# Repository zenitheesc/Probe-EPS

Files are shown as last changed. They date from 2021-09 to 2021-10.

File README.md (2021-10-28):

<h1 align="center" style="color:white; background-color:black">Probe-EPS</h1>
<h4 align="center">Eletrical power system for stratospheric probes, using Zenith Stack</h4>

<p align="center">
	<a href="http://zenith.eesc.usp.br/">
    
    </a>
    <a href="https://eesc.usp.br/">
    
    </a>
    <a href="https://github.com/zenitheesc/Probe-EPS/blob/main/LICENSE">
    
    </a>
    <a href="https://github.com/zenitheesc/Probe-EPS/issues">
    
    </a>
    <a href="https://github.com/zenitheesc/Probe-EPS/commits/main">
    
    </a>
    <a href="https://github.com/zenitheesc/Probe-EPS/graphs/contributors">
    
    </a>
    <a href="https://github.com/zenitheesc/Probe-EPS/commits/main">
    
    </a>
    <a href="https://github.com/zenitheesc/Probe-EPS/issues">
    
    </a>
    <a href="https://github.com/zenitheesc/Probe-EPS/pulls">
    
    </a>
</p>

<p align="center">
    <a href="#environment-and-tools">Environment and Tools</a> •
    <a href="#z-hub">Z-Hub</a> •
    <a href="#aroca-(battery)-eps">Aroca (Battery) EPS</a> •
    <a href="#london-(power)-eps">London (Power) EPS</a>
</p>

This configuration of the Eletrical power system requires a board that monitors the charger and battery, in addition to performing thermal control.

## Environment and tools

This system was designed using Eagle v.9.4.2

## Z-Hub

<p align = "center">
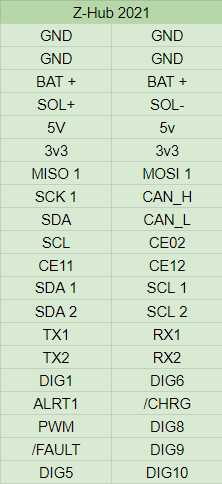
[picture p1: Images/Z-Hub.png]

</p>

<a href="https://github.com/zenitheesc/Probe-EPS/tree/main/Hardware/Aroca_EPS-v.2.0"><h2>Aroca (Battery) EPS</h2></a>

<p align = "center">
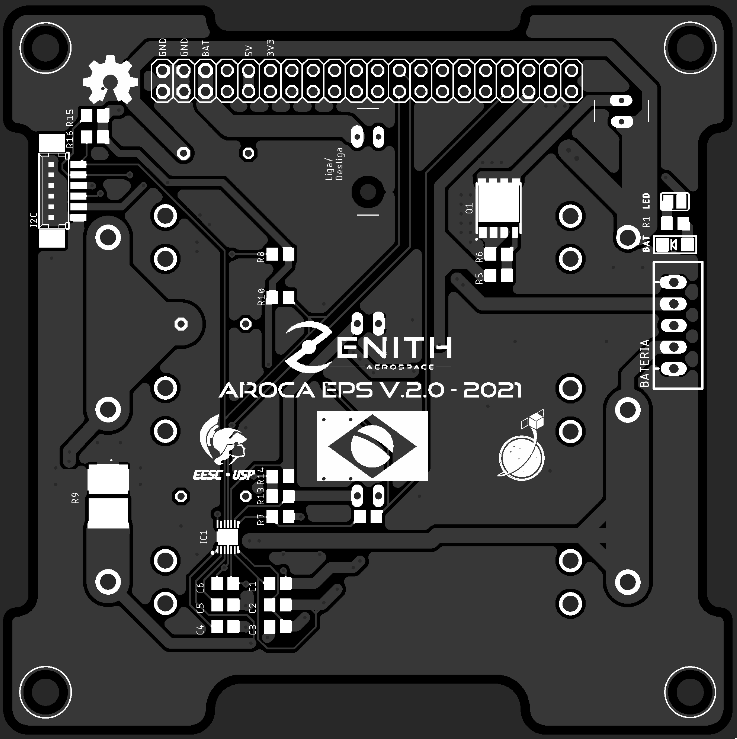
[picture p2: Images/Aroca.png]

</p>

This subsystem is primarily responsible for the active thermal control of the batteries, in addition to supporting battery monitoring and load balancing

<a href="https://github.com/zenitheesc/Probe-EPS/tree/main/Hardware/London_EPS-v.2.0"><h2>London (Power) EPS</h2></a>

<p align = "center">
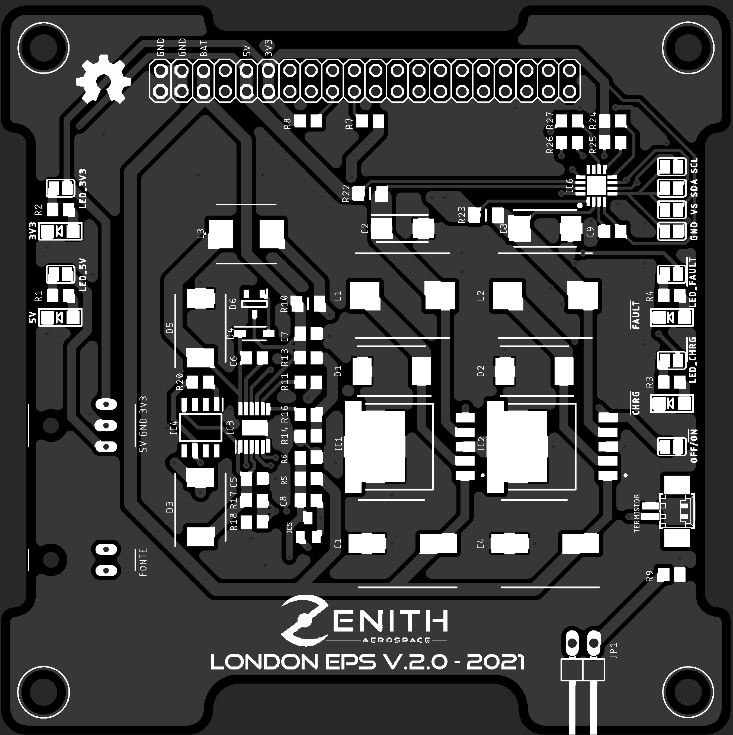
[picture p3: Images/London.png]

</p>

Functioning as an extension of the previous subsystem, it performs conversions of battery voltage levels to the levels requested within the hardware, making the necessary distribution, as well as controlling the loading of batteries through solar panels.

---

<p align="center">
    <a href="http://zenith.eesc.usp.br">
    
    </a> 
    <a href="https://www.facebook.com/zenitheesc">
    
    </a> 
    <a href="https://www.instagram.com/zenith_eesc/">
    
    </a>

</p>
<p align = "center">
<a href="zenith.eesc@gmail.com">zenith.eesc@gmail.com</a>
</p>

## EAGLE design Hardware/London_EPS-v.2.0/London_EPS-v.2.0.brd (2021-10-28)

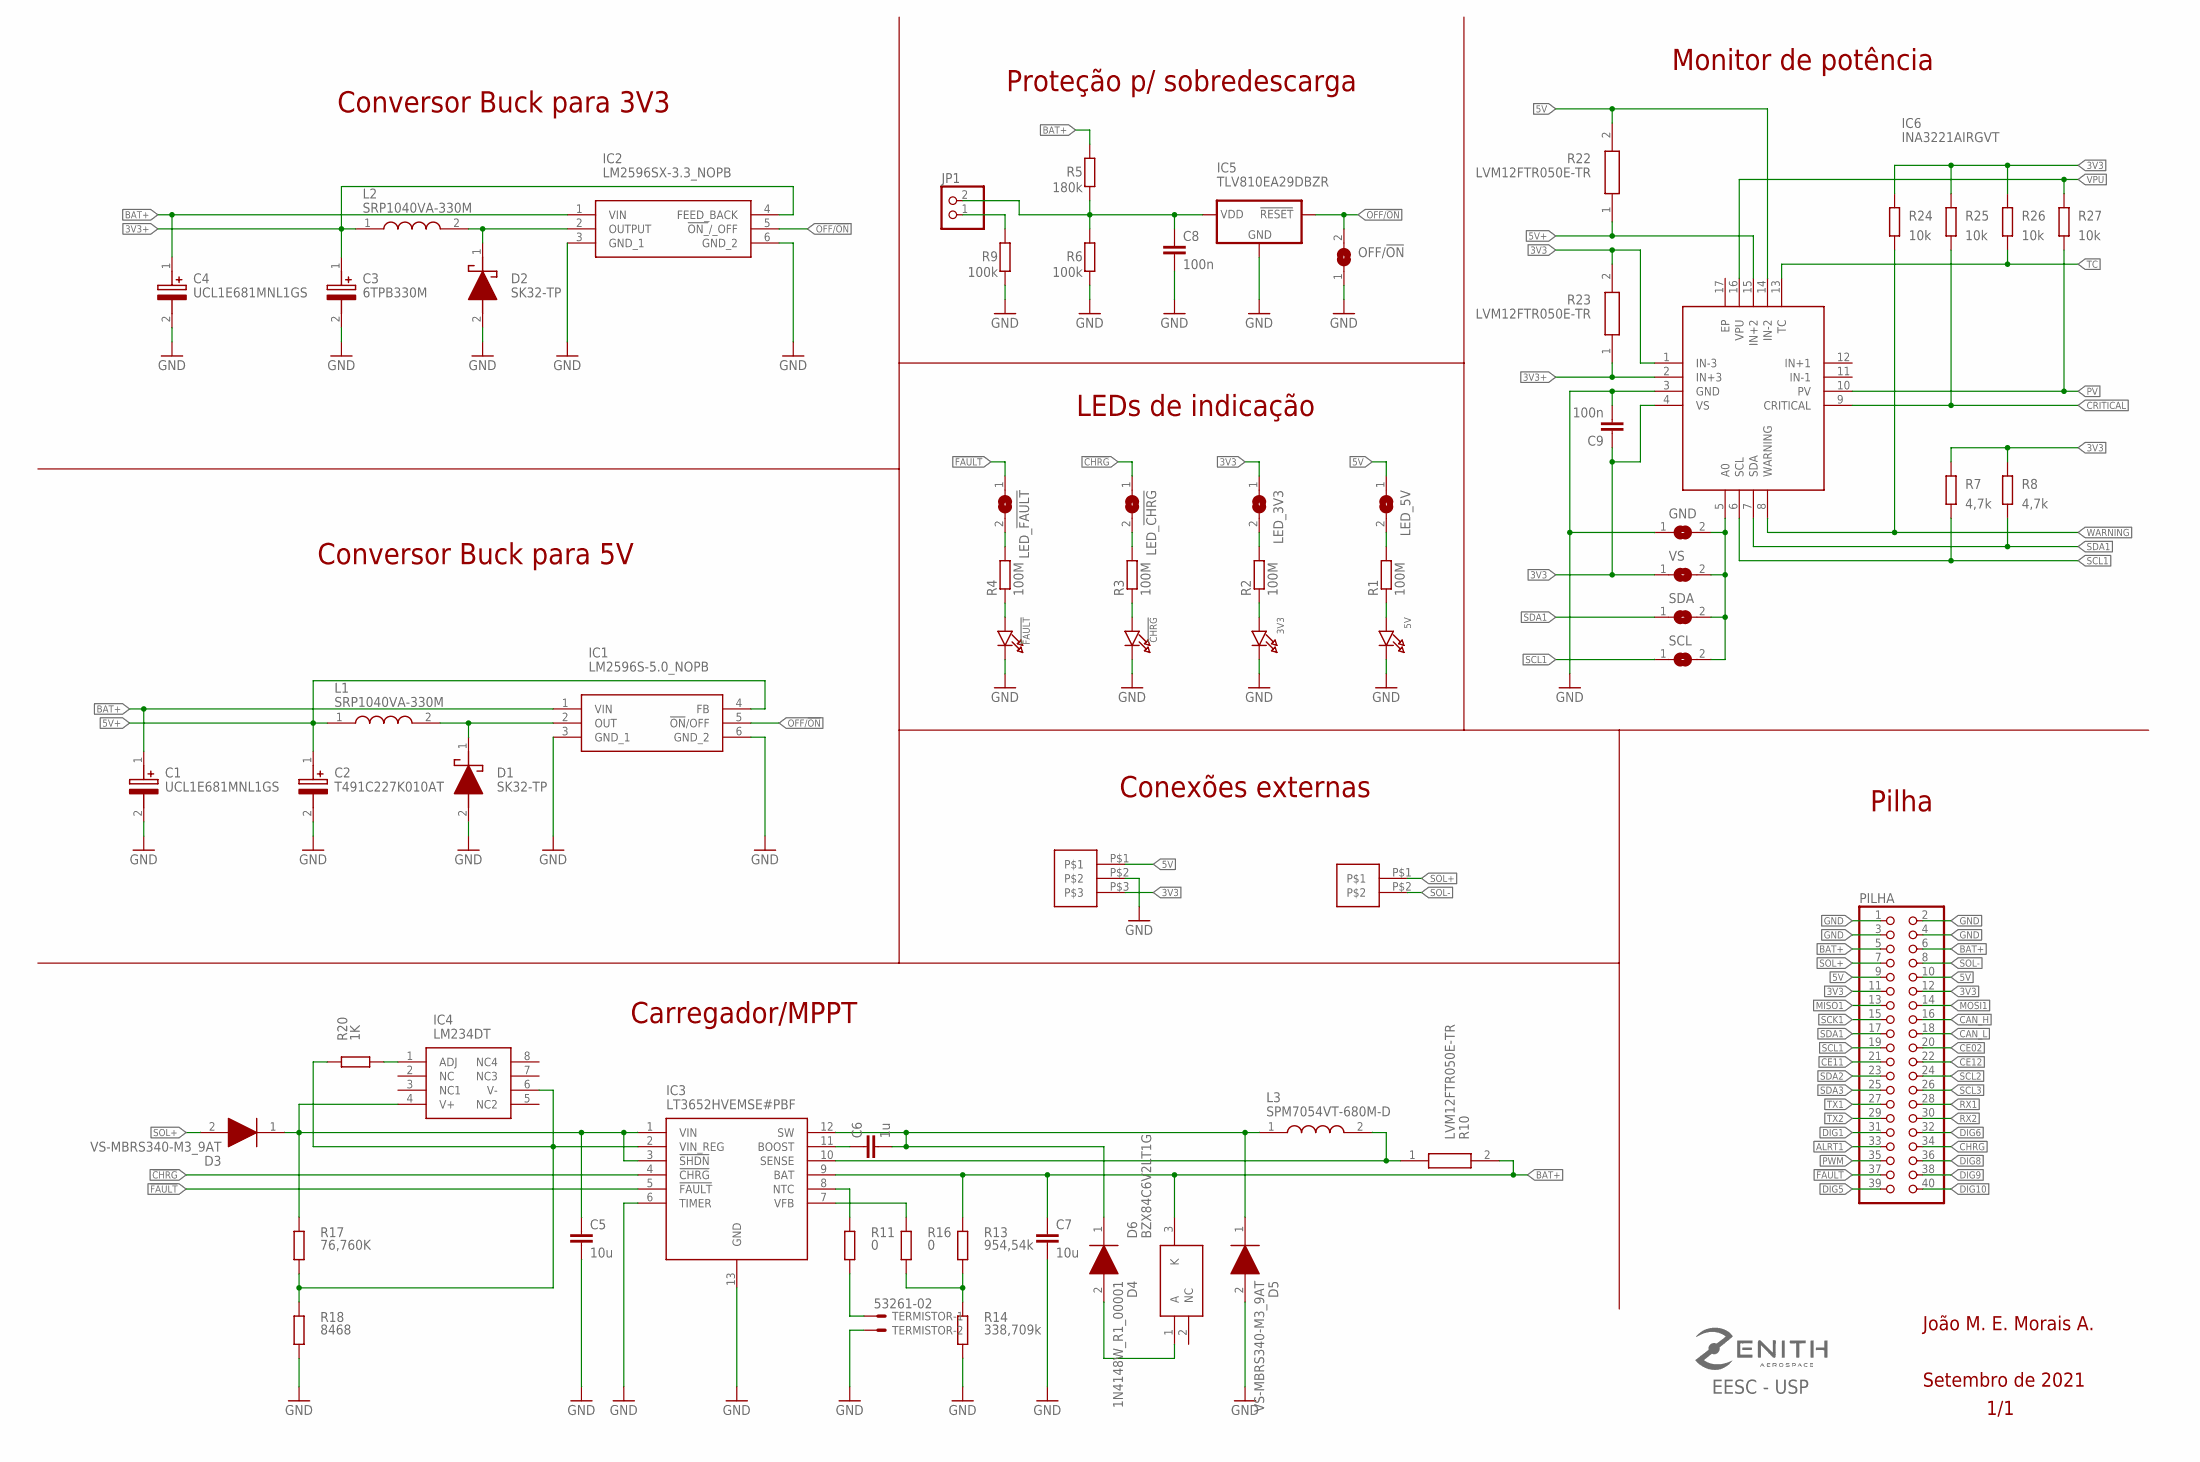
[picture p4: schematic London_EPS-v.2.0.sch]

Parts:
3V3, 5V: LED1206; CHIPLED_1206
!CHRG: LED1206; CHIPLED_1206
!FAULT: LED1206; CHIPLED_1206
C1, C4: UCL1E681MNL1GS; CAPAE1030X1400N
C2: T491C227K010AT; CAPPM6032X280N
C3: 6TPB330M; 10TPF150ML
C5, C7: 10u; C0805
C6: 1u; C0805
C8, C9: 100n; C0805
D1, D2: SK32-TP; DIOM7959X262N@1
D3, D5: VS-MBRS340-M3_9AT; DIOM7959X262N
D4: 1N4148W_R1_00001; SOD3816X135N
D6: BZX84C6V2LT1G; SOT96P237X111-3N
GND: SOLDERJUMPERREFLOW_NOPASTE; SOLDERJUMPER_REFLOW_NOPASTE
IC1: LM2596S-5.0_NOPB; KTT0005B
IC2: LM2596SX-3.3_NOPB; KTT0005B
IC3: LT3652HVEMSE#PBF; SOP65P490X110-13N
IC4: LM234DT; SOIC127P600X175-8N
IC5: TLV810EA29DBZR; SOT23
IC6: INA3221AIRGVT; QFN65P400X400X100-17N
JP1: PINHD-1X2/90; 1X02/90
L1, L2: SRP1040VA-330M; INDPM110100X400N
L3: SPM7054VT-680M-D; SPM7054VT
LED_3V3, LED_5V: SOLDERJUMPERREFLOW_NOPASTE; SOLDERJUMPER_REFLOW_NOPASTE
LED_!CHRG: SOLDERJUMPERREFLOW_NOPASTE; SOLDERJUMPER_REFLOW_NOPASTE
LED_!FAULT: SOLDERJUMPERREFLOW_NOPASTE; SOLDERJUMPER_REFLOW_NOPASTE
OFF/!ON: SOLDERJUMPERREFLOW_NOPASTE; SOLDERJUMPER_REFLOW_NOPASTE
PILHA: PINHD-2X20; 2X20
R1, R2, R3, R4: 100M; R0805
R5: 180k; R0805
R6, R9: 100k; R0805
R7, R8: 4,7k; R0805
R10, R22, R23: LVM12FTR050E-TR; RESC3016X70N
R11, R16: 0; R0805
R13: 954,54k; R0805
R14: 338,709k; R0805
R17: 76,760K; R0805
R18: 8468; R0805
R20: 1K; R0805
R24, R25, R26, R27: 10k; R0805
SCL: SOLDERJUMPERREFLOW_NOPASTE; SOLDERJUMPER_REFLOW_NOPASTE
SDA: SOLDERJUMPERREFLOW_NOPASTE; SOLDERJUMPER_REFLOW_NOPASTE
TERMISTOR: 53261-02
U$1: S02B-XASS-1
U$2: S03B-XASS-1
VS: SOLDERJUMPERREFLOW_NOPASTE; SOLDERJUMPER_REFLOW_NOPASTE

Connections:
3V3: C9.1, IC6.1 (IN-3), IC6.4 (VS), LED_3V3.1, PILHA.11, PILHA.12, R7.2, R8.2, R23.2, R24.2, R25.2, R26.2, U$2.P$3, VS.1
3V3+: C3.1 (+), IC2.4 (FEED_BACK), IC6.2 (IN+3), L2.1, R23.1
5V: IC6.14 (IN-2), LED_5V.1, PILHA.9, PILHA.10, R22.2, U$2.P$1
5V+: C2.1 (+), IC1.4 (FB), IC6.15 (IN+2), L1.1, R22.1
!CHRG: IC3.4 (!CHRG), LED_!CHRG.1, PILHA.34
!FAULT: IC3.5 (!FAULT), LED_!FAULT.1, PILHA.37
ALRT1: PILHA.33
BAT+: C1.1 (+), C4.1 (+), C7.1, D6.3 (K), IC1.1 (VIN), IC2.1 (VIN), IC3.9 (BAT), PILHA.5, PILHA.6, R5.1, R10.2, R13.1
CAN_H: PILHA.16
CAN_L: PILHA.18
CE02: PILHA.20
CE11: PILHA.21
CE12: PILHA.22
CRITICAL: IC6.9 (CRITICAL), R25.1
DIG1: PILHA.31
DIG5: PILHA.39
DIG6: PILHA.32
DIG8: PILHA.36
DIG9: PILHA.38
DIG10: PILHA.40
GND: 3V3.C, 5V.C, !CHRG.C, !FAULT.C, C1.2 (-), C2.2 (-), C3.2 (-), C4.2 (-), C5.2, C7.2, C8.2, C9.2, D1.2 (A), D2.2 (A), D5.2 (A), GND.1, IC1.3 (GND_1), IC1.6 (GND_2), IC2.3 (GND_1), IC2.6 (GND_2), IC3.6 (TIMER), IC3.13 (GND), IC5.2 (GND), IC6.3 (GND), OFF/!ON.1, PILHA.1, PILHA.2, PILHA.3, PILHA.4, R6.2, R9.2, R14.2, R18.2, TERMISTOR.2, U$2.P$2
MISO1: PILHA.13
MOSI1: PILHA.14
unnamed: 5V.A, R1.1
unnamed: LED_5V.2, R1.2
unnamed: 3V3.A, R2.1
unnamed: LED_3V3.2, R2.2
unnamed: !CHRG.A, R3.1
unnamed: D2.1 (K), IC2.2 (OUTPUT), L2.2
unnamed: LED_!CHRG.2, R3.2
unnamed: D1.1 (K), IC1.2 (OUT), L1.2
unnamed: !FAULT.A, R4.1
unnamed: LED_!FAULT.2, R4.2
unnamed: C8.1, IC5.3 (VDD), JP1.2, R5.2, R6.1
unnamed: GND.2, IC6.5 (A0), SCL.2, SDA.2, VS.2
unnamed: JP1.1, R9.1
unnamed: IC3.10 (SENSE), L3.2, R10.1
unnamed: IC3.8 (NTC), R11.1
unnamed: R11.2, TERMISTOR.1
unnamed: C6.2, D4.1 (K), D5.1 (K), IC3.12 (SW), L3.1
unnamed: IC3.7 (VFB), R16.1
unnamed: R13.2, R14.1, R16.2
unnamed: C6.1, IC3.11 (BOOST)
unnamed: C5.1, D3.1 (K), IC3.1 (VIN), IC3.3 (!SHDN), IC4.4 (V+), R17.1
unnamed: IC3.2 (VIN_REG), IC4.6 (V-), R17.2, R18.1, R20.1
unnamed: IC4.1 (ADJ), R20.2
unnamed: D4.2 (A), D6.1 (A)
OFF/!ON: IC1.5 (!ON!/OFF), IC2.5 (!ON_!/_OFF), IC5.1 (!RESET), OFF/!ON.2
PV: IC6.10 (PV), R27.1
PWM: PILHA.35
RX1: PILHA.28
RX2: PILHA.30
SCK1: PILHA.15
SCL1: IC6.6 (SCL), PILHA.19, R7.1, SCL.1
SCL2: PILHA.24
SCL3: PILHA.26
SDA1: IC6.7 (SDA), PILHA.17, R8.1, SDA.1
SDA2: PILHA.23
SDA3: PILHA.25
SOL+: D3.2 (A), PILHA.7, U$1.P$1
SOL-: PILHA.8, U$1.P$2
TC: IC6.13 (TC), R26.1
TX1: PILHA.27
TX2: PILHA.29
VPU: IC6.16 (VPU), R27.2
WARNING: IC6.8 (WARNING), R24.1

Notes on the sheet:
C:/Users/marcu/Desktop/Ensino Superior/Graduação - Eng Elétrica/Zenith/zenith-v2.bmp
EESC - USP
Setembro de 2021
1/1
João M. E. Morais A.
Pilha
Monitor de potência
Carregador/MPPT
Conversor Buck para 5V
Conversor Buck para 3V3
Proteção p/ sobredescarga
LEDs de indicação
Conexões externas

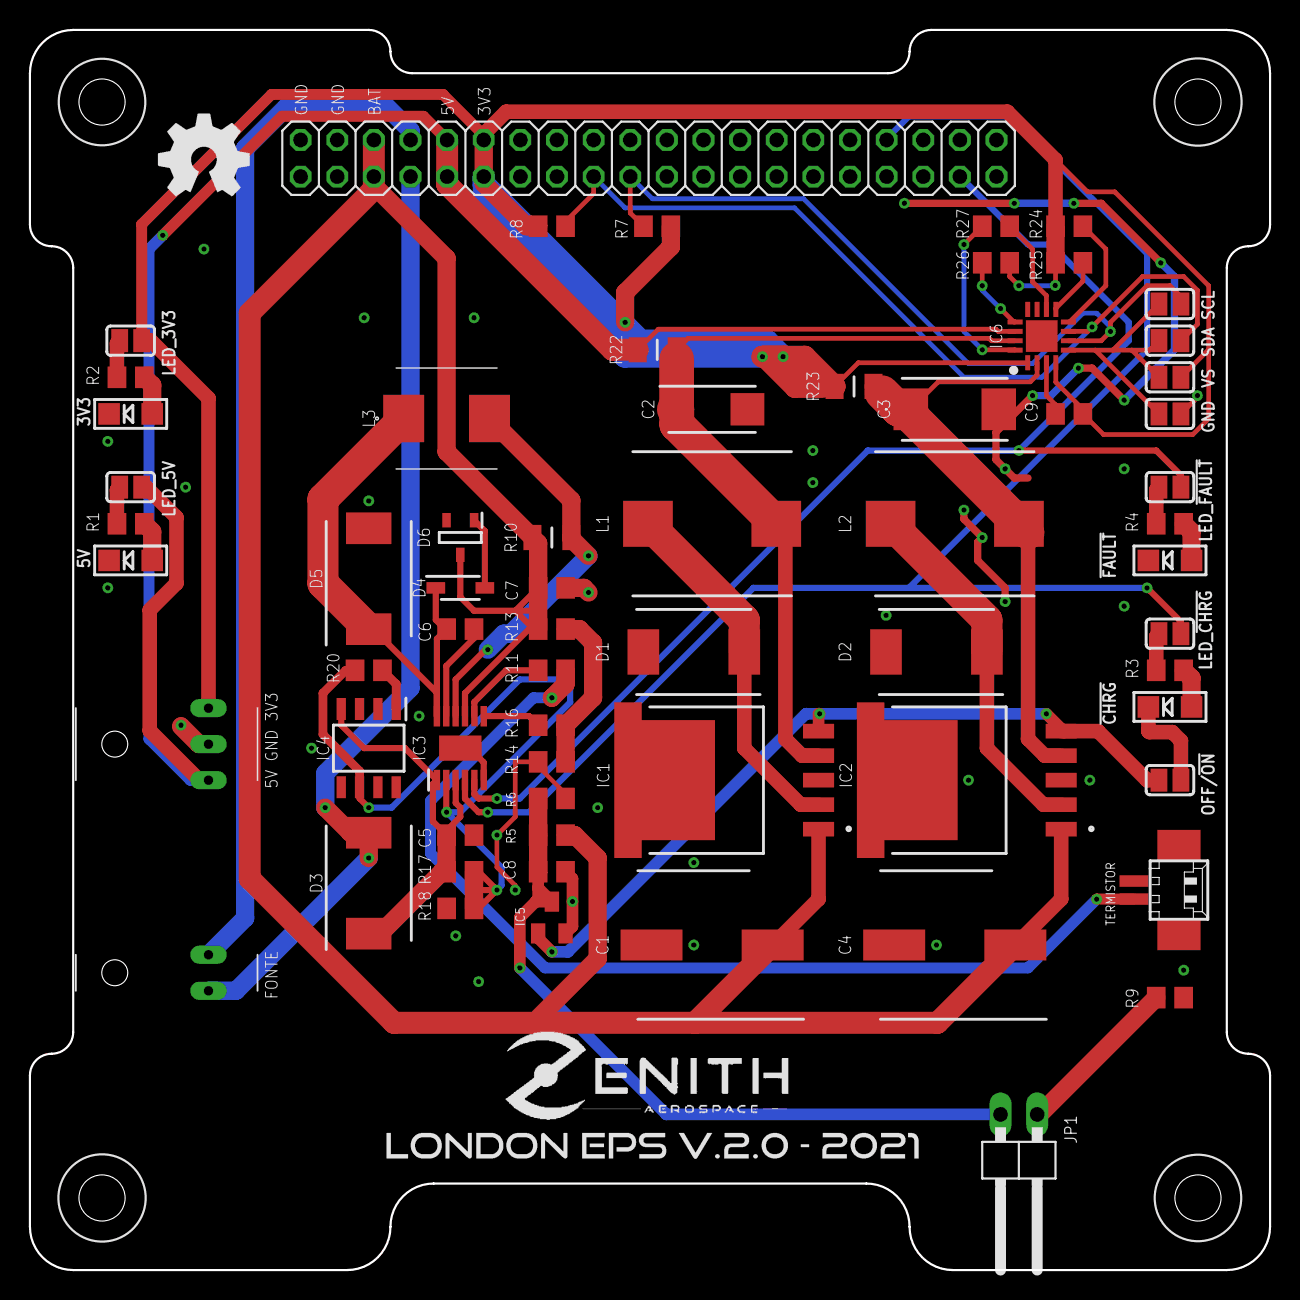
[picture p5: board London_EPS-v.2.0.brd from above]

Board: 2 copper layers, 86.0 x 86.0 mm, 65 parts (0 on the bottom side), 42 nets.

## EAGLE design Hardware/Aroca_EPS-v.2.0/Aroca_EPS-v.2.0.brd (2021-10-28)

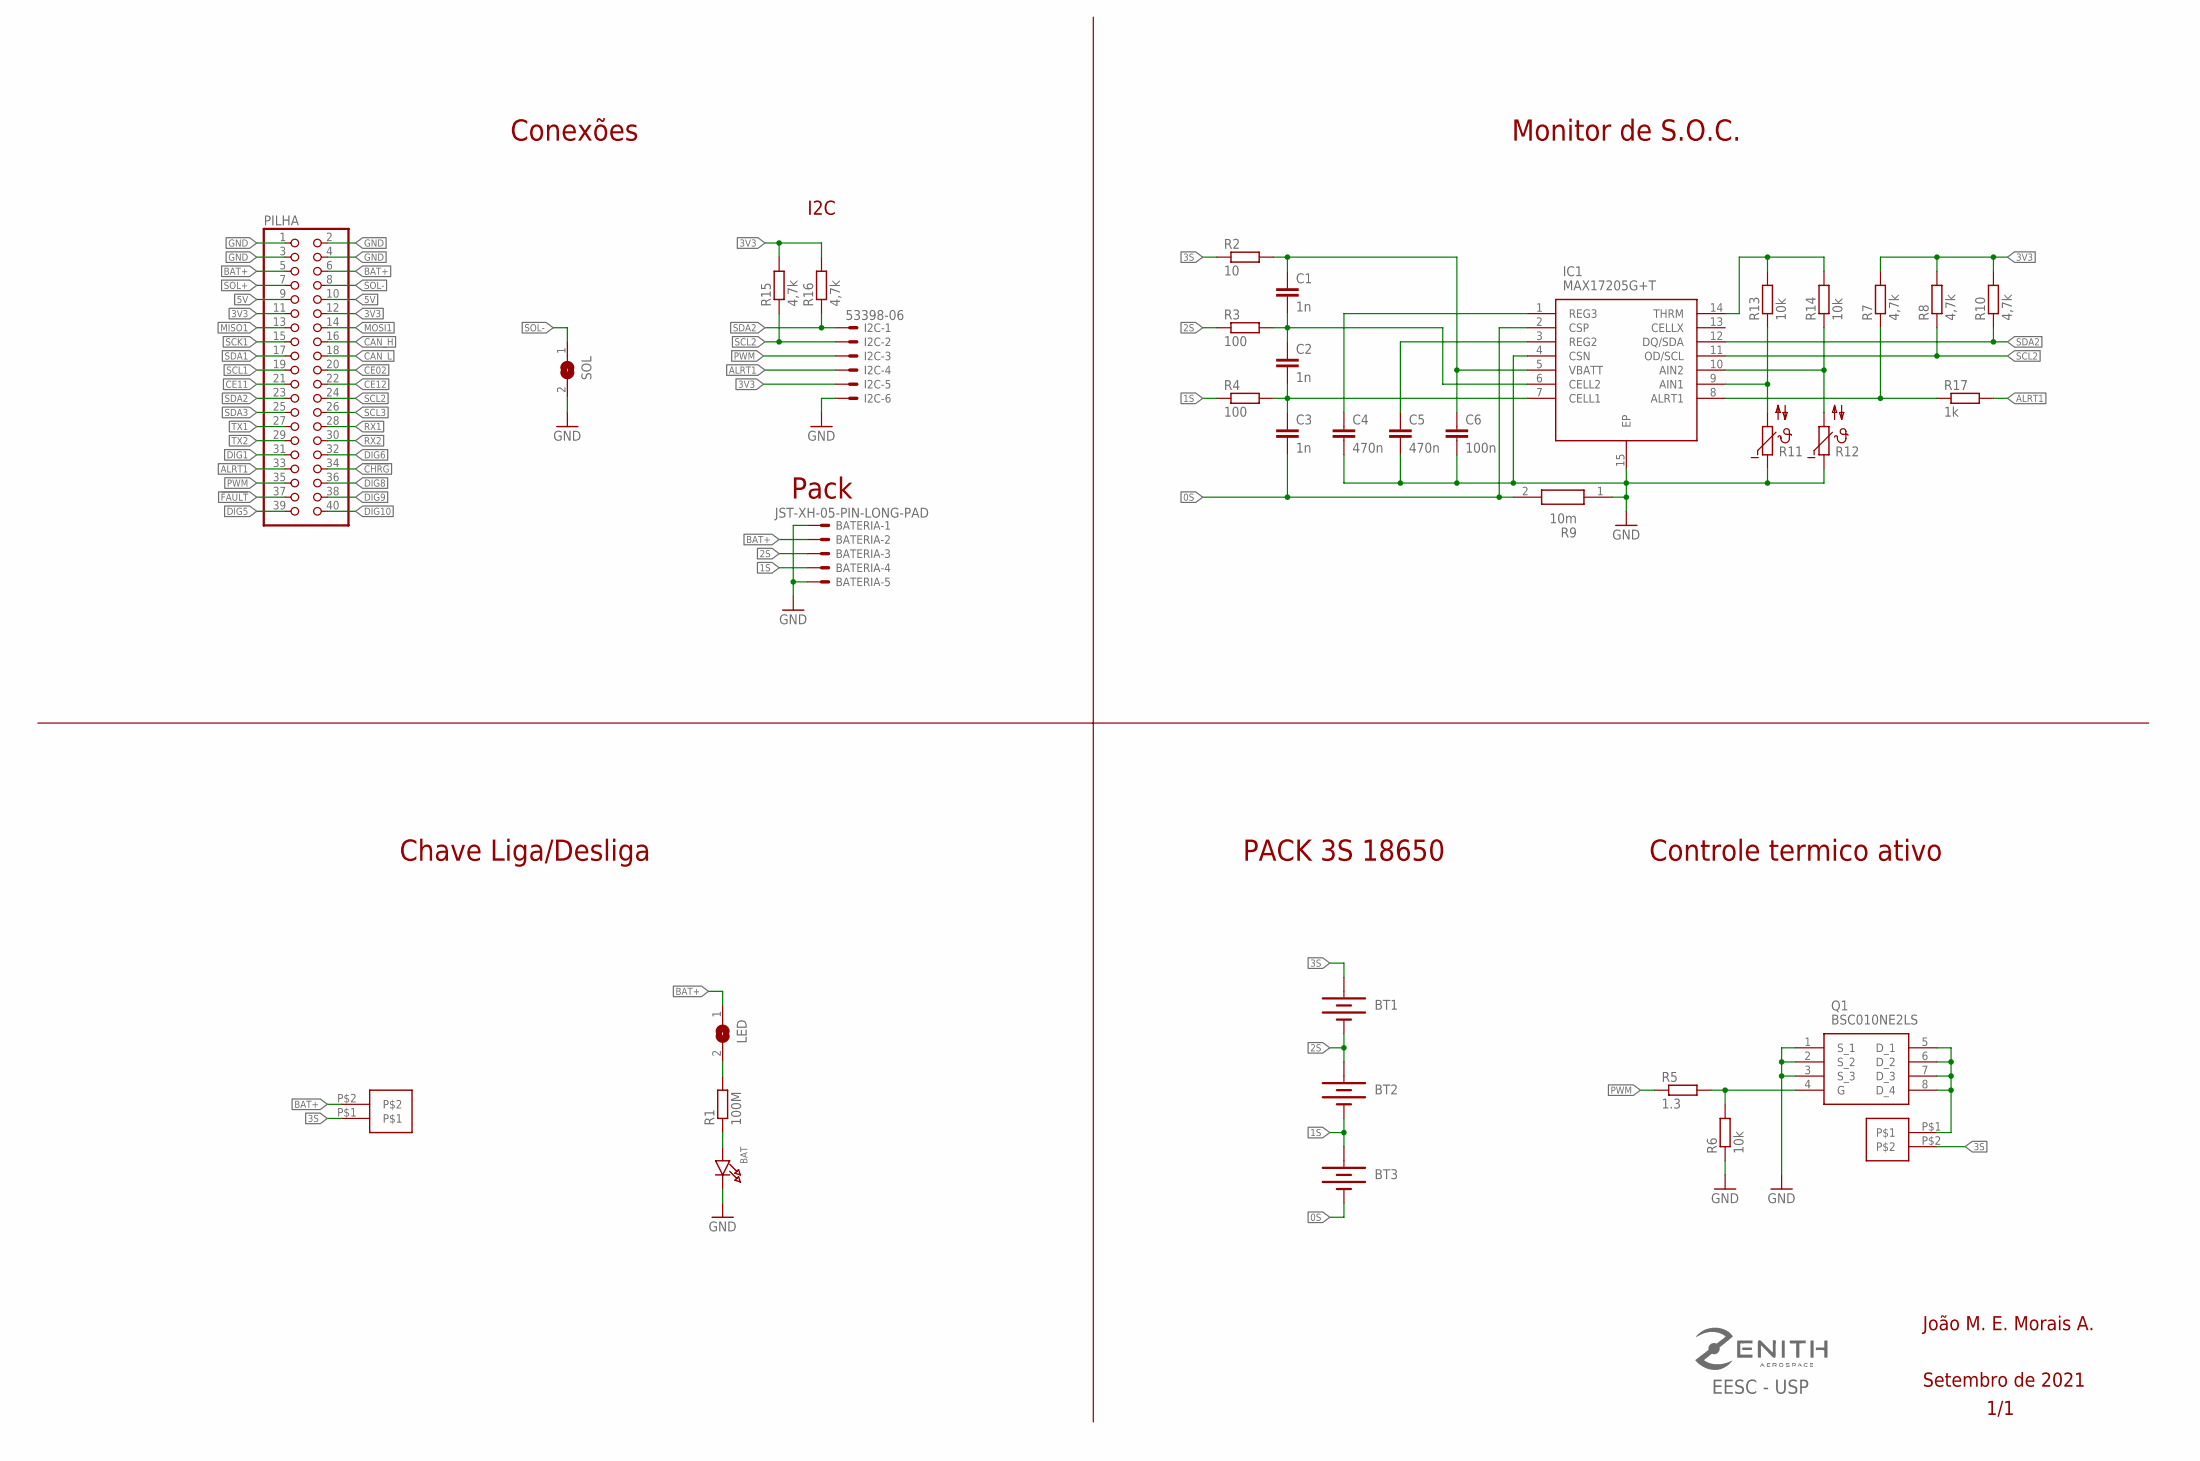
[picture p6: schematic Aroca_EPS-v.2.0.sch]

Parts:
BAT: LED1206; CHIPLED_1206
BATERIA: JST-XH-05-PIN-LONG-PAD; JST-XH-05-PACKAGE-LONG-PAD
BT1, BT2, BT3: BATTERY-18650; BATTERY_18650-HOLDER
C1, C2, C3: 1n; C0805
C4, C5: 470n; C0805
C6: 100n; C0805
I2C: 53398-06
IC1: MAX17205G+T; SON40P300X300X80-15N
LED: SOLDERJUMPERREFLOW_NOPASTE; SOLDERJUMPER_REFLOW_NOPASTE
PILHA: PINHD-2X20; 2X20
Q1: BSC010NE2LS; PG-TDSON-8
R1: 100M; R0805
R2: 10; 0204/7
R3, R4: 100; 0204/7
R5: 1.3; R0805
R6, R13, R14: 10k; R0805
R7, R8, R10, R15, R16: 4,7k; R0805
R9: 10m; GMR320HJBFA10L0
R11, R12: NTC640; P640
R17: 1k; R0805
SOL: SOLDERJUMPERREFLOW_NOPASTE; SOLDERJUMPER_REFLOW_NOPASTE
U$1: S02B-XASS-1
U$2: B02B-XASK-1

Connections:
0S: BT3.GND@1 (-), C3.2, IC1.2 (CSP), R9.2
1S: BATERIA.4, BT2.GND@1 (-), BT3.PWR@1 (+), R4.1
2S: BATERIA.3, BT1.GND@1 (-), BT2.PWR@1 (+), R3.1
3S: BT1.PWR@1 (+), R2.1, U$1.P$1, U$2.P$2
3V3: I2C.5, PILHA.11, PILHA.12, R7.2, R8.2, R10.2, R15.2, R16.2
5V: PILHA.9, PILHA.10
!CHRG: PILHA.34
!FAULT: PILHA.37
ALRT: IC1.8 (ALRT1), R7.1, R17.1
ALRT1: I2C.4, PILHA.33, R17.2
BAT+: BATERIA.2, LED.1, PILHA.5, PILHA.6, U$1.P$2
CAN_H: PILHA.16
CAN_L: PILHA.18
CE02: PILHA.20
CE11: PILHA.21
CE12: PILHA.22
DIG1: PILHA.31
DIG5: PILHA.39
DIG6: PILHA.32
DIG8: PILHA.36
DIG9: PILHA.38
DIG10: PILHA.40
GND: BAT.C, BATERIA.1, BATERIA.5, C4.2, C5.2, C6.2, I2C.6, IC1.4 (CSN), IC1.15 (EP), PILHA.1, PILHA.2, PILHA.3, PILHA.4, Q1.1 (S_1), Q1.2 (S_2), Q1.3 (S_3), R6.1, R9.1, R11.1, R12.1, SOL.2
MISO1: PILHA.13
MOSI1: PILHA.14
unnamed: BAT.A, R1.1
unnamed: LED.2, R1.2
unnamed: Q1.4 (G), R5.2, R6.2
unnamed: C4.1, IC1.1 (REG3)
unnamed: C5.1, IC1.3 (REG2)
unnamed: C1.1, C6.1, IC1.5 (VBATT), R2.2
unnamed: C2.2, C3.1, IC1.7 (CELL1), R4.2
unnamed: C1.2, C2.1, IC1.6 (CELL2), R3.2
unnamed: IC1.14 (THRM), R13.2, R14.2
unnamed: IC1.9 (AIN1), R11.2, R13.1
unnamed: IC1.10 (AIN2), R12.2, R14.1
PWM: I2C.3, PILHA.35, R5.1
RL: Q1.5 (D_1), Q1.6 (D_2), Q1.7 (D_3), Q1.8 (D_4), U$2.P$1
RX1: PILHA.28
RX2: PILHA.30
SCK1: PILHA.15
SCL1: PILHA.19
SCL2: I2C.2, IC1.11 (OD/SCL), PILHA.24, R8.1, R15.1
SCL3: PILHA.26
SDA1: PILHA.17
SDA2: I2C.1, IC1.12 (DQ/SDA), PILHA.23, R10.1, R16.1
SDA3: PILHA.25
SOL+: PILHA.7
SOL-: PILHA.8, SOL.1
TX1: PILHA.27
TX2: PILHA.29

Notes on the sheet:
C:/Users/marcu/Desktop/Ensino Superior/Graduação - Eng Elétrica/Zenith/zenith-v2.bmp
EESC - USP
Setembro de 2021
1/1
João M. E. Morais A.
Conexões
PACK 3S 18650
Controle termico ativo
Monitor de S.O.C.
Chave Liga/Desliga
I2C
Pack

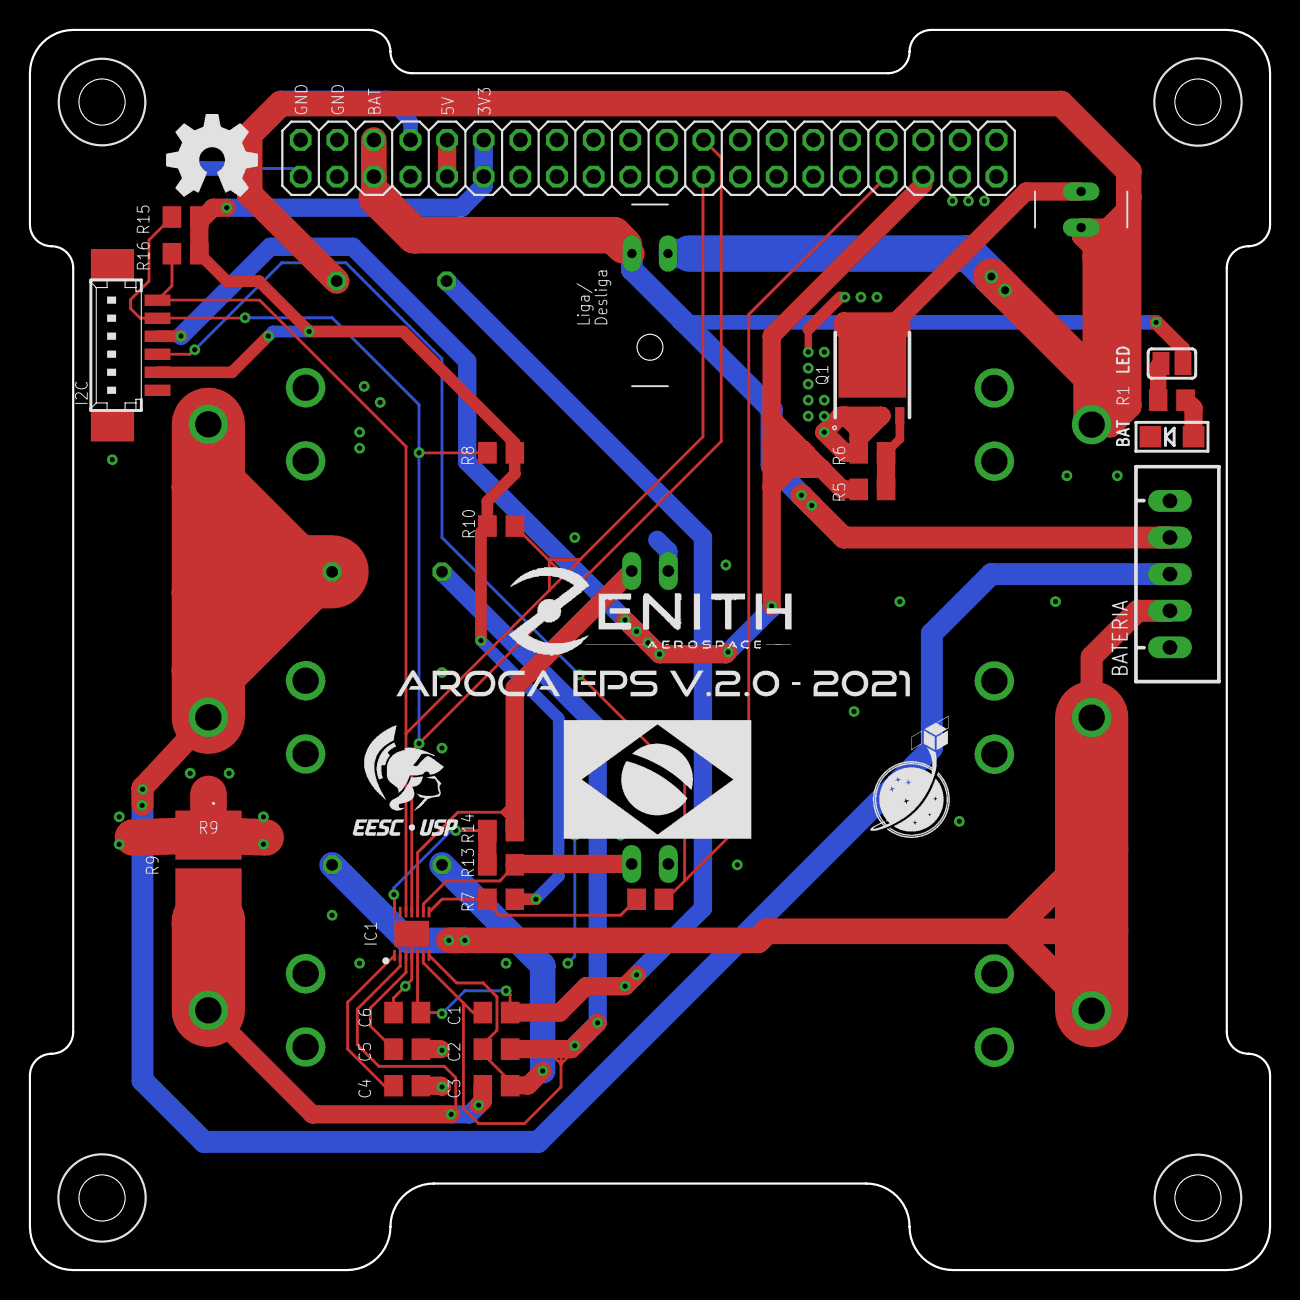
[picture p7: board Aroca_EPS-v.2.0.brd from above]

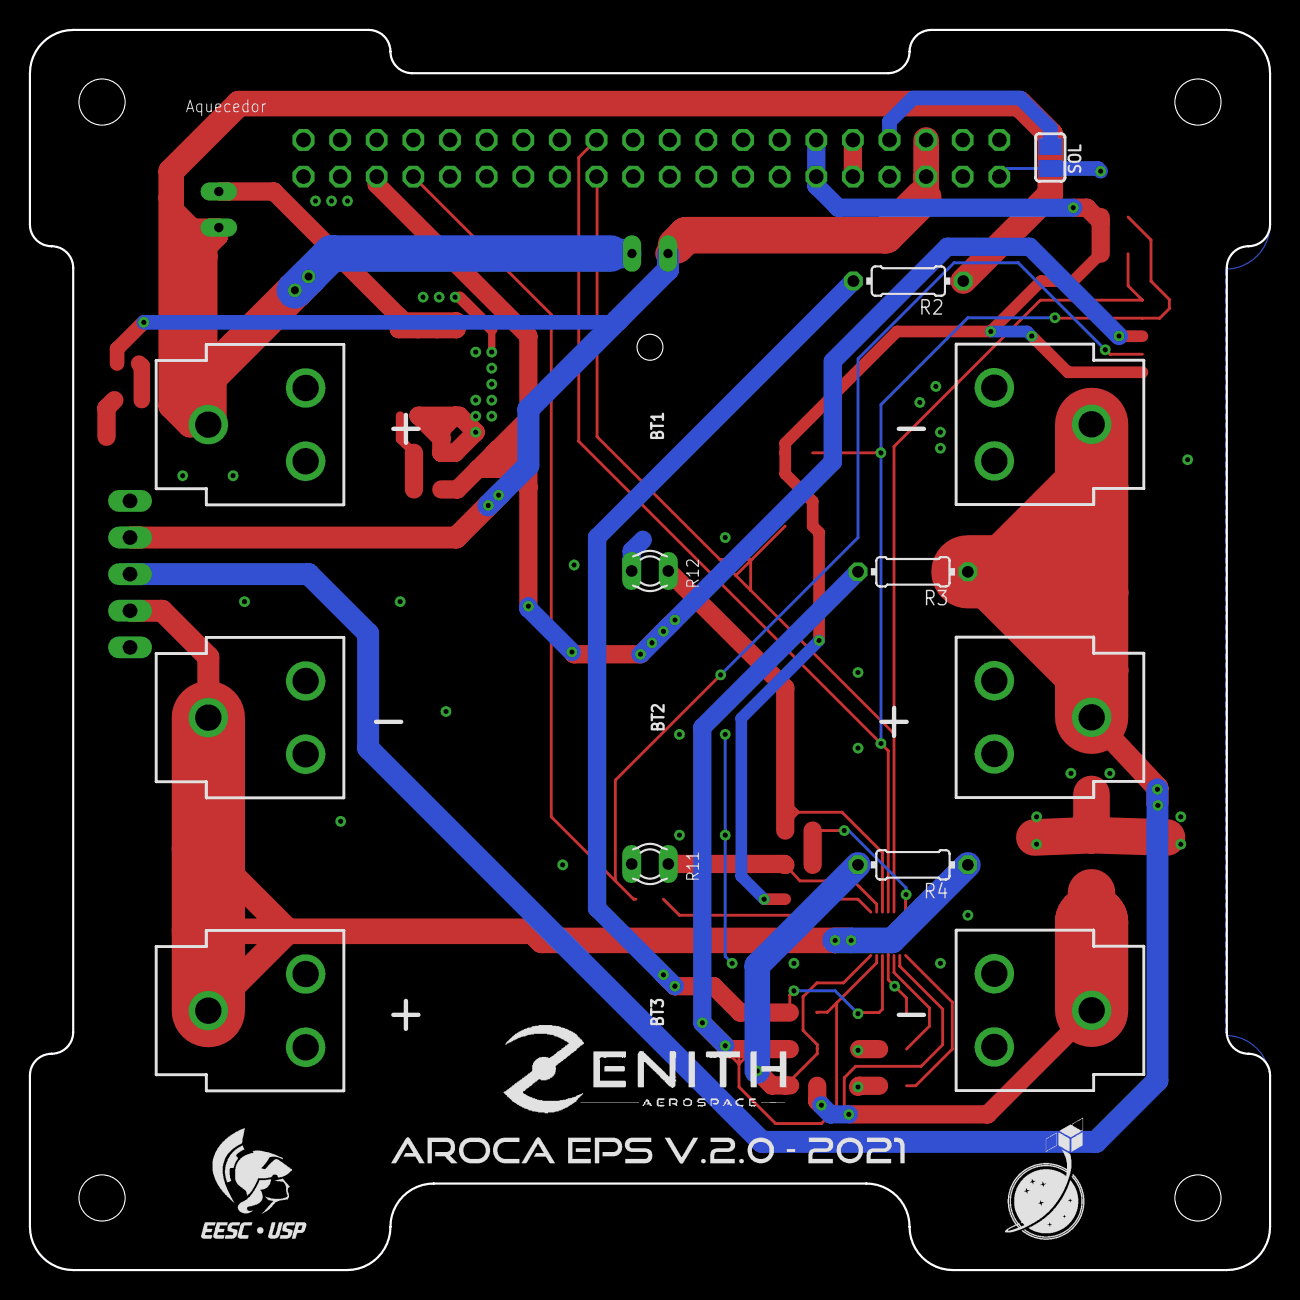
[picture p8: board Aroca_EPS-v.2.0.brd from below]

Board: 2 copper layers, 86.0 x 86.0 mm, 36 parts (9 on the bottom side), 26 nets.

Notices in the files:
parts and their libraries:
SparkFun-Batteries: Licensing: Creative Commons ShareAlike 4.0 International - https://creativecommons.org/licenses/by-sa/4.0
